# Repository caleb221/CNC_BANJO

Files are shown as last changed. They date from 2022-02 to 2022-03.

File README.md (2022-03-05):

# CNC_BANJO
This is a full sized 5 string Open Back Banjo I decided to make.<br>
It uses nylong strings, planetary geared tuners, a calfskin head and is Texas themed.<br>
The rim and neck are both made from Poplar, while the fretboard is made from Oak.

 
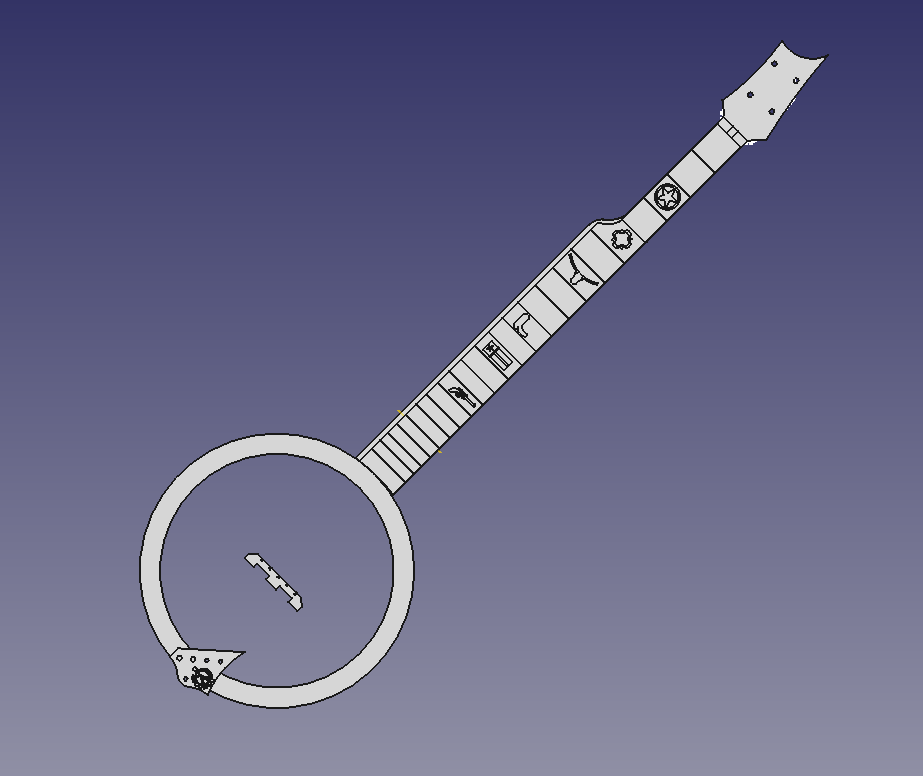
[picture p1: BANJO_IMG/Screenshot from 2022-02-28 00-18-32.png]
 
 

# Model
  The banjo1.fcstd File is the CAD File for the whole banjo.<br>
  
  Fret lengths were found using the <a href="https://www.ekips.org/tools/guitar/fretfind2d/">FretFind2D Tool</a>. 
 
  A scale length of 26.375'' or 669.925mm was used.
  
  This is a standard full sized 5 String Open Back Banjo.
  
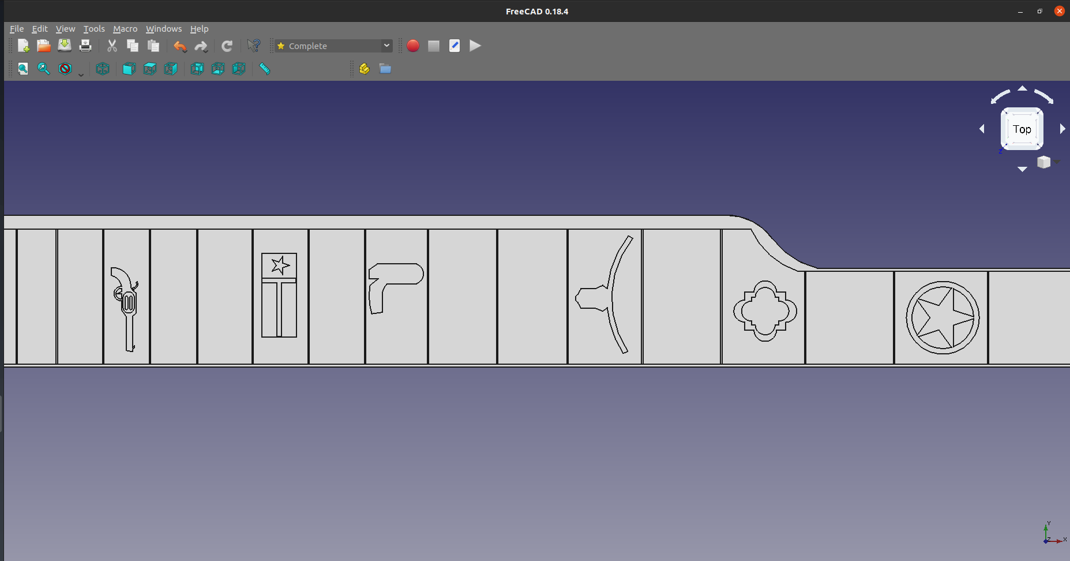
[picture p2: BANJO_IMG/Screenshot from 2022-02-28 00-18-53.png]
  
  
# BUILD

  <b>RIM Ring:</b><br>
   To prepare the wood from a stick to a ring (without a steam bender or lathe)
   first cut out 8 segments of your wood stock according to<br> <a href="https://github.com/caleb221/CNC_BANJO/blob/main/NON_CNC_PLANS/BluestemBanjoRimSegmentGuide.pdf"> Blue Stem Rim Segment Guide (copy)</a>.
   I cut 36 segments of the 8 segment 11'' rim, which totaled 4 rings and a depth of about 3'' for the rim.
    
   Glue the segments together using either a jig (probably better) or a band clamp which is what I used.
   
   After the glue dries and all 4 segments are prepared, use the CNC to cut out the rings.
   
   Once the rings are cut, use the dowel holes to line up the rings and glue all 4 segments together.
   
   Once you have what should look like a rough rim, use the CNC as an upside down router table to smooth things out on both the inner and outer diameters.
   I used a flush trim bit to do this.
   
   Once it is flush, I cut a small lip around the outer diameter. 
   
   Once this process was finished, I measured out the angles needed for the hardware.
   
   This can be found as the hardware_angles array in teh freecad file
   
   I used the drill press to make these 8 holes. Along with 2 7/16'' holes on each end for the 1/4'' threaded dowel rod, tailpiece and neck attachment.
   
   <b>I had pictures of this process, but halfway through my phone decided to die, losing those pictures forever</b>
    
   
    
    
    Note: The model is a bit oversized, which allows for discrepencies that arise when the rings are glued together and so that the 11'' inner diameter can be reached using the flush trim bit.
    Most of the wood preparation measurements can be found in the NON_CNC folder.
    There are also bits of information on building jigs and how to make one without a CNC.
    
  <b>RIM Hardware:</b><br>
    <br> 
    <b>Tension Hoop:</b>
      
    Get the 3 foot Steel flat bar and bend it into a ring.
    
    Use the rim to measure the exact size of the ring, and mark it. It should be oversized by a few inches.
    
    place the bent steel into a vise where it can be brazed together.
    
    The inner part of the steel bar should meet the measured mark, with the excess on the outer part.
    
    Heat the steel ring until it is red hot and braze the steel with flux and a bronze rod. 
    
    Use an Angle grinder to remove the excess flat bar, and deburr across the top.
    
  <br>
    
  <b>J hooks and Brackets:</b>
  
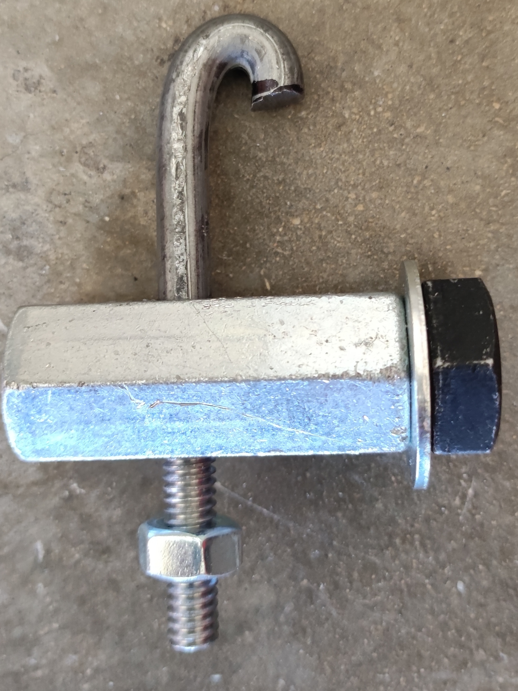
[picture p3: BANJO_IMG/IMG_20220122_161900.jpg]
   
   
   Measure the approximate depth of your rim and use it for the length . 
    
   Grab the 1/4'' steel rod and put it into a vise. 
    
   using as little rod as possible create a 90 degree bend, then hammer that bend until you can see a clear hook.
    
   Cut of the excess in the hook using an angle grinder, and cut it to length (should be approximately 3/4 your rim depth).
    
   Thread at least 1/2 the length of the J hook using 1/4'' round die and cleaning with a 1/4'' hex die..
    
   Repeat until you have 8 hooks

   Use one 1/2'' coupling nut, a 1/2'' bolt and appropriate washer and thread it into place in the rim blank.
   
   Once it is in, get your steel hoop and place it where it fits snugly onto the rim.
   
   Grab a J-hook and measure the approximate location in which it will hold the hoop and sit in the coupling nut.
   
   The coupling nut should be much longer than desired.
   
   Use the mark from the J-hook to determine how much excess there is in the coupling nut.
   
   Cut out the marked hole through the coupling nut with the drill press.
   
   Use the angle grinder to cut off the excess markings on the coupling nut.
   
   repeat until you have 8 brackets.
   
   Determine if your bolts fit snugly without hitting the J-hooks, mine where a bit too long.
   
   If needed, cut down the 8 bolts to a length where they will tighten down fully without touching the J-hooks.
   
    
     
  
  <b>RIM Finishing steps:</b><br>
  
  At this point, apply any wood finish desired to the rim and let it dry. I used Boiled Linseed Oil and some minwax golden Oak.
  
  Once dry (a few days usually), test how the hardware fits together, make sure all hooks grab onto the tension ring.
  
  Also make sure the tension ring holds down the flesh hoop tightly.
  
  Disassemble and prepare the parts for the last time.
  
  Soak a calfskin (at least 13'' in diameter) in warm water for at least 30 minutes.
  
  Wrap the skin in the flesh hoop and get it in place on the rim.
  
  Put the tension hoop in place along with the J-Hooks.
  
  
  
  
  Tighten the J-Hooks <b>SLOWLY</b>. 
  
  Cut off the excess skin using a box cutter or any knife.
  
  
  
  The skin will dry out over the next day, tighten as it will allow.
  
  <b>NECK:</b><br>
  
  Glue up the appropriate boards. I used Poplar but any hardwood will do great!
  
  Cut out the neck blank using the CNC. This will require you to flip the workpiece.
  
  The top side should be cut first as it contains the "truss" rod and that must be centered within the neck.
  
  Cut the backside. Round out the edges with a 3/4'' roundover bit.
  
  Cut out the heel blank, glue it to the neck blank using dowels to align.
  
  Glue the 3/4'' steel square bar into the neck using silicon or glue of your choice.
  
  
  
  Cut out the appropriate headstock holes.
  
  Cut out the 5th string peg.
  
  Drill 2 holes at a 5 degree angle for the hangar bolt attachment to the rim.
  
  <b>Finger Board:</b><br>
  
  Prepare any 1/4'' hardwood slat onto the CNC.
  
  Cut out the artwork and contour, then backfill the artwork with epoxy resin.
  
  
  
  
  Fret the neck or fill in the fret slots with epoxy for a "fretless" banjo.
  
  level, sand, and crown the frets if thats the way you went. 
  
  I had enough fret wire for 12 frets, and the rest are epoxied in. A half and half compromise
  
  Glue onto the neck.
  
  <b>MISC:</b><br>
   Flesh Hoop: I used a 1/8'' Brass rod threaded and held together with a coupling nut.
   
   TailPiece: I used extra wood from the fretboard and a copper wire tied onto a 1/4'' bolt sticking out the back. 
   
   Bridge: While I did design this, I used a bridge I had obtained earlier from a banjo I built in High School.
   
# Tools
    Open Builds LEAD1010 CNC (or anything 
    Drill Press Vise
    Drill Press (the cheaper harbor freight one did this job just fine for me)
    Angle Grinder
    Power Drill
    MAP/Butane Blow torch
    Taps / Dies (SAE 1/4'' and 1/8'')
    Pull Saw
    Draw knife / spokeshave 
    Wood/Metal Rasp
    Metal Files
    Miter Box with 22.5 Degree slot
    Clamps
    Safety stuff
# BOM
    Poplar wood (1''X3'' X ~14' is what I used)
    Oak wood  (1/4'' X 3'' X ~4')
    Calfskin 16'' diamter (thin, but a thick one would work just as well)
    1/4'' steel round stock ( ~5 Feet)
    1/4'' steel square stock (~3 feet)
    1/8'' Brass rod 
    1/2'' coupling nuts
    1/2'' X 1'' Bolt
    1/2'' Flat washer
    18 guage steel flat bar
    1/4'' hanger bolt
    1/4'' coupling nut
    1/4'' X 1' threaded rod
    1/4'' nut
    1/4''X 2'' bolt
    1/8'' coupling nut
    Fret wire
    Imitation bone Nut blank
    Banjo Planetary tuning pegs (with 5th string peg)
    bridge (if not making the one designed)

# Consumables:
    Epoxy Resin
    Brazing Rods
    Super Glue
    Epoxy Resin
    Mica Powder
    Boiled Linseed Oil/Japan Dryer
    Sand Paper





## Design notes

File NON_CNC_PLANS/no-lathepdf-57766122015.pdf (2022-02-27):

# No lathe? – No Problem!

J. D. Michne

I was in the Northeastern Woodworkers Association (NWA) Learning Center, teaching some members how to build a cedar stripped canoe. There were some other members working on banjoes in Ken’s class there. That looked like a neat woodworking project, so I told Ken if he ever did another class, sign me up. He did, and since I was between building boats, I became a novice luthier. I don’t need a banjo and can’t play one (yet), but the craftsmanship challenge would be exciting.

Ken’s method of building the rim consists of accurately cutting six identical blocks with 30⁰ angles on the ends, and gluing them together into a perfect hexagon. Make three or four assemblies, and then glue the whole stack together.

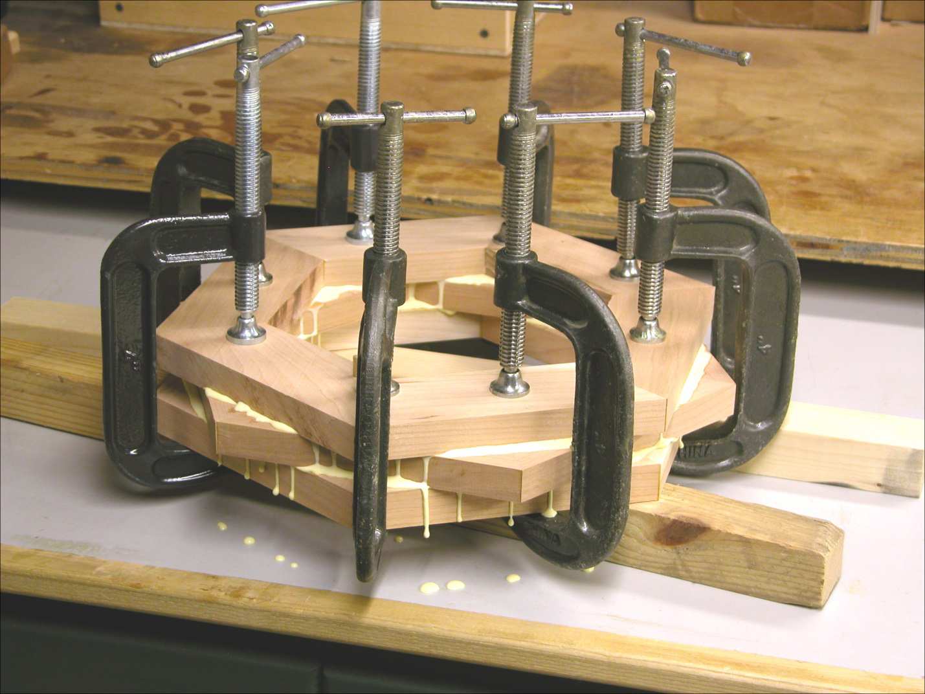
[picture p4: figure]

Then we rough-cut the outside round to just a bit oversize on a band saw. One of the students brought in a long-bladed jig saw, and roughed out the inside to near round. The whole thing was then mounted on a backer board and faceplate and turned round on a lathe. Another lathe session two weeks later brought the piece to perfectly round at the correct final dimensions.

Ken’s classes are every other Friday afternoon, so there was a lot of time between sessions. When I have a lot of extra time, I think. When I think, I can be dangerous…

What if one of the joints in the hexagon was not glued, then sprung open enough to slip the band saw blade though it? Cutting the inside of the individual rings would be easy. For that matter, if the rings were cut accurately enough to require just sanding to final dimension after gluing, the need for a lathe would be eliminated. Furthermore, the width of the blocks required to get a circle out of a polygon would be reduced if there were eight blocks instead of six. Off to the computer and CAD. I drew two concentric circles ³
/4" apart, and then surrounded them with an octagon inside and out.

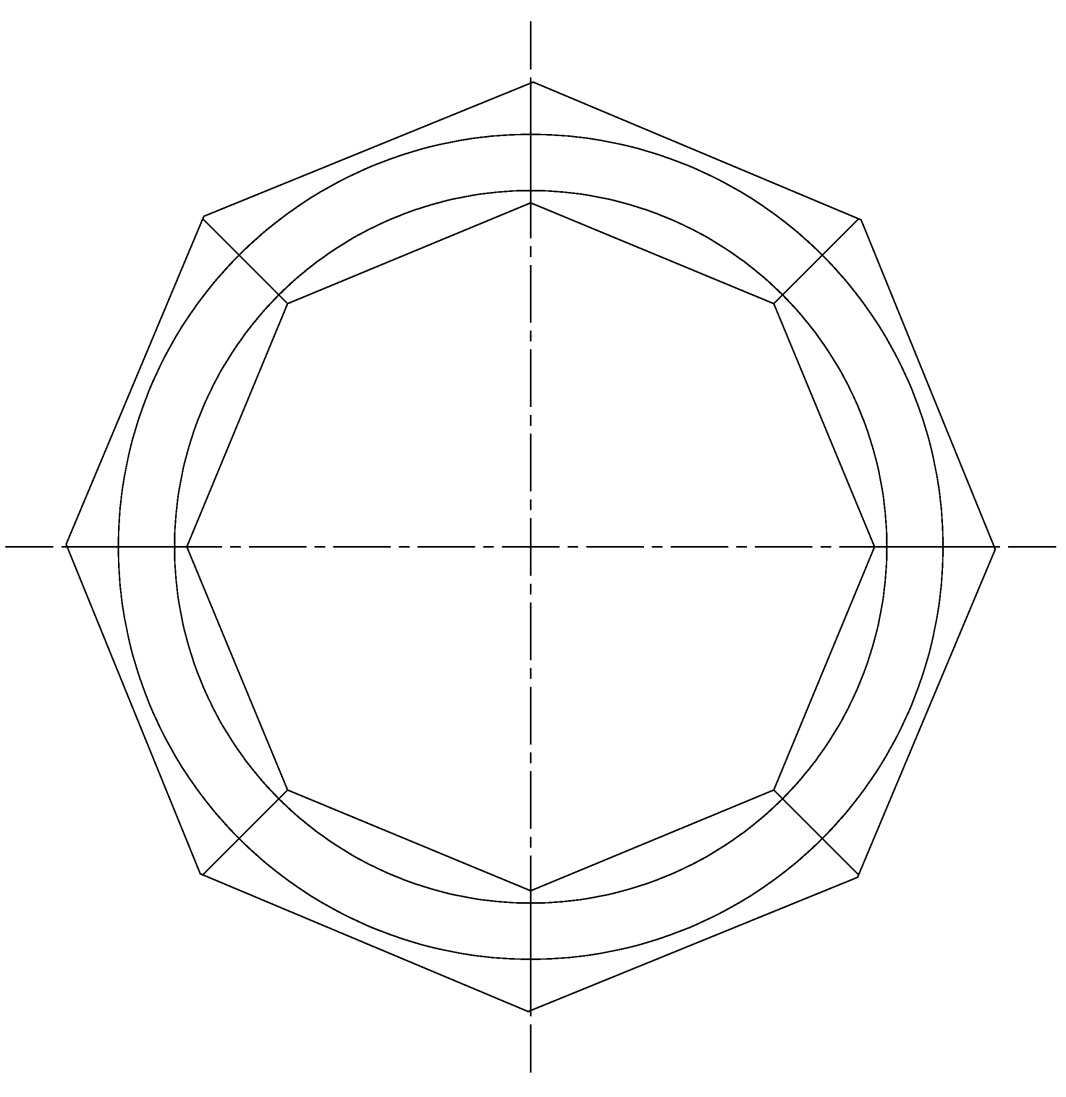
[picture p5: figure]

The dimensions of the segments are 1¹

/2" wide, 4³
/4" on the long side, and a complementary angle of 22¹
/2

⁰ between the long side and the cut ends. The ring is 11" outside diameter, ³
/4"
thick¹
. With the dimensions now defined, I could use a sled to cut the identical segments on the table saw.

I had a sled set up to cut the 30⁰ angles for my class banjo, so changing the angle to exactly
22¹
/2⁰ was next. How was I to get that angle, and as close to exact as possible? Without some sort of reference device, it would have to be by trial and error, commonly called “sneaking up on

1

In Ken’s class, resonator banjo rims are ³

/4" thick; open backs are 1
/2".

it”. I made sure the miter gage on the table saw was exactly square to the blade (the plate, not the teeth), and the pointer on the head was set exactly to 0⁰. Then I rotated the miter gage head so the pointer was as close to 67¹
/2⁰ as I could estimate, and locked it. I cut that angle on a piece of ¹
/4" plywood, and used it as a preliminary reference to set up the sled. I cut the reference piece the same width as the desired blocks, and around a foot long.

The sled looks like this, showing a few blocks already cut and another being run through:

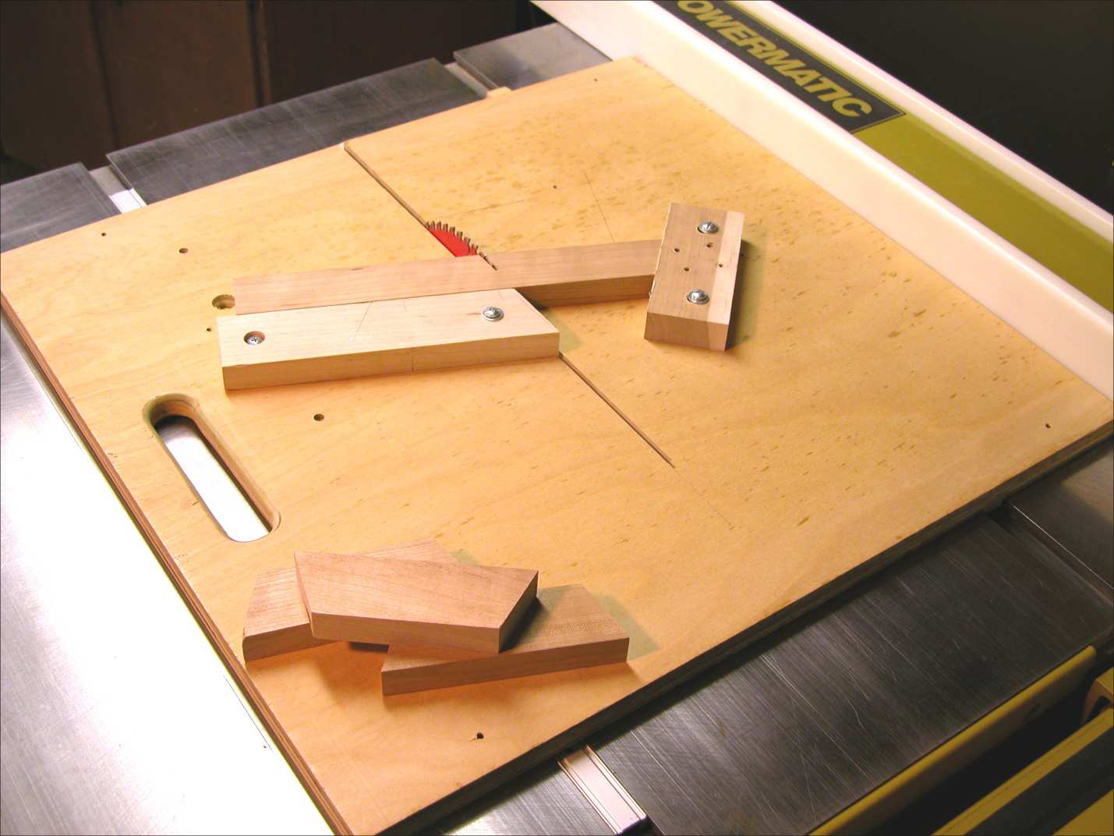
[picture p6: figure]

The base is ³
/4" hardwood plywood, shop-acclimated and flat. I added an additional bar to ride in the second miter gage slot on the saw table, so that the blade was approximately centered on the base. The sled has to be rock-solid yet slide smoothly with no side-to-side slop, so I butted the saw’s fence up to the edge of the base and locked it.

To determine the initial placement of the infeed fence, I set the angled end of the plywood reference against the blade and scribed its edge on to the base with a sharp pencil. The infeed fence was screwed to the base at the scribed mark with two screws – the one on the left is a pivot, and the one on the right is through an oversize hole. This permits a slight amount of play that can be used to fine-tune the cutting angle before tightening the screw. The piece used for the fence was initially longer than needed so that it extended beyond the cut line. It was trimmed after it was mounted.

The outfeed stop block is simply a convenient piece of scrap wood screwed down as a stop. Its position defines the length of the cut segment, which can be determined using the plywood angle reference. Simply make a mark on the reference at the proper dimension (4³
/4" on the long side)
and align the mark at the tip of the outside of a saw tooth as if it would be cut, and screw the block down. Both screw holes are over-size, again to permit minor adjustments.

This is a good place to mention some nitty gritty details easily overlooked. Ignoring them can result in problems as you go along. Remember, using a lathe produces the perfect round. We want to be able to come as close as possible to perfectly round without a lathe. Achieving this requires your tools to be set up as precisely as possible.

First, the table saw must be accurately aligned – fence parallel to the blade, blade parallel to the miter gage slot and square to the table. A good sharp blade capable of making smooth cuts is essential. I prefer the 7¹

/4" Freud Diablo D0760R, 60 teeth, with a ¹ /16" kerf. The band saw table must be square to the blade, and likewise for any sander you may use. The jointer tables must be aligned and the fence square to the tables. Test cuts in scrap will show the need for any adjustments.

The sled now has to be set up to make perfect cuts. This may take a while, but if you were lucky making the reference piece it should go well. Using scrap wood, make some pieces 1¹
/2" wide
and a couple of feet long. They should be ³
/4" thick, but need not be precise. We only want to verify the cutting angle – 1-by pine will do.

Make an angle cut on one end of a test piece. Insure there are no chips or sawdust anywhere on the sled where the stock will be placed. A chip brush works well here. Positioning the stock for the next cut with even a small chip under it can cause a skewed cut. Rotate and position the test piece on the sled with the cut end against the stop block, and cut a block. Any time you are about to make a cut, make sure the cut end is firmly against the stop block, and the stock is held tightly against the infeed fence. The goal here is reproducible precision in the cut blocks. Make eight blocks.

Dry-assemble the blocks into an octagon on a flat surface and clamp them as if they were a glue-up assembly. The Merle clamp works well in Ken’s class, but at home, I use a band clamp with shop-made shaped clamping cauls at the joints. (See the picture on the next page.) Examine the clamped assembly closely. There should be no gaps anywhere and the corners should all align. Press each piece to the table to ensure all surfaces of the assembly are in the same plane. If there are any gaps, the cutting angle of the fence needs adjustment. Loosen the screw closest to the blade, and very slightly pivot the fence just a hair one way or the other depending on where the gaps in the assembly are. This adjustment should be just barely perceptible. Then try again. Don’t try to trim the ends of each block – this is a safety issue.

If all is well, you could start on the real thing, but don’t do it yet. Use full-size test pieces to assemble an octagon before committing to the real wood. Apply glue liberally to each joint except for the last one. Leave this joint dry, and clamp the assembly together. The dry joint will be tight when the glue cures and the clamp is released. This joint will become the gateway for the band saw blade for sawing the inside round. Don’t try to spring the joint open just yet. Forcing it open could cause a failure in one of the glued joints. Simply mark the joint for now. Let the glue dry for about 30 minutes, and remove most of the squeezed out glue with a putty knife. This makes it easier for drum sanding later. The heat of sanding softens the glue, which then gums up the sand paper.

With the cutting angle set and a successful test glue-up, the next step is to make wood for the real thing. That is, joint one surface of the raw stock, then joint one edge square to the jointed face, thickness plane the raw surface to bring it parallel to the jointed face, and finally rip it to final width with the jointed square edge against the saw fence. This is a very important sequence. In order to get perfect glue joints on a flat and uniformly thick assembly, the component parts must be straight, flat, square, true, level, plumb, dry, etc., - “close enough” not allowed.

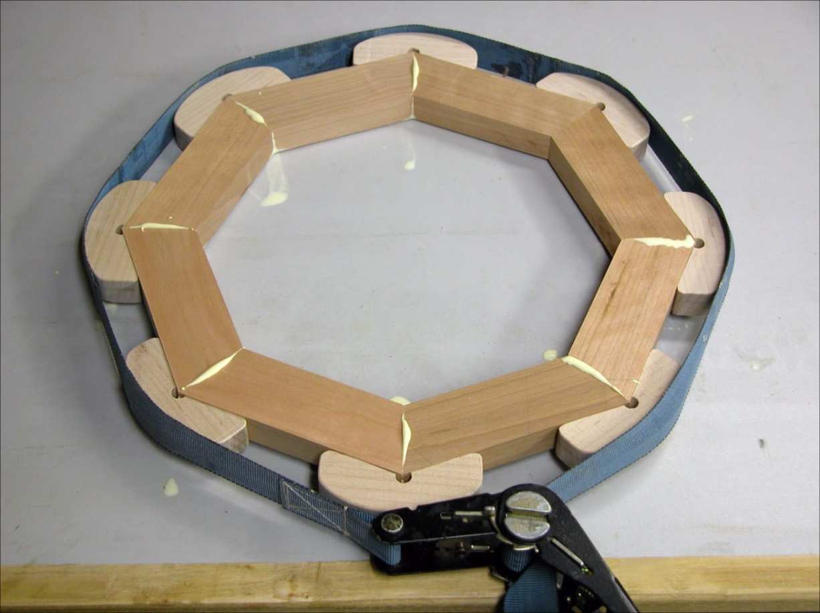
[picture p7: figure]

Glued octagon – Note the one dry joint.
How many assemblies are needed to make a banjo? If the wood is nominally ³
/4" thick, four
rings in a stack will yield a pot about 3" high. The top ring will be either shaped for a metal tone ring or chamfered for using the top ring as the tone ring. The bottom ring can always be thinned to the final desired height after assembly. For purposes of this discussion, I will assume four rings.

Scrape the dried glue off as much as possible without being surgical about it. It is better to leave a little bit rather than scraping a divot into the wood.

Drum-sand both sides of the assemblies. Examine the sanded surfaces closely, and repeat until the entire surface has the same texture and there are no glue remnants. You are now ready to make round rings.

The reference for turning a ring on the lathe is the axis of the lathe, which extends through the stock being turned. Whatever is turned about the axis can be brought perfectly round by the application of various tools. What is the reference for making a ring from wood without a lathe? The center of the circle is not defined, since it does not exist in a real object. The solution is to attach a temporary and reproducible reference center.

Note in the drawing on page 2 that there are two centerlines crossing at right angles. These lines also intersect joints in the octagon. For any opposing pair of joints, there are equivalent pairs of joints at exact right angles to it. Here is the solution to the reference center problem. By attaching a plywood disk cut in a perfect circle to the octagon, the center of the disk becomes the center of the octagon.

To make the reference disk, rip a piece of ¹
/4" plywood about a half inch wider than the desired outside diameter of the final ring. Without changing the table saw fence, turn the ripped piece 90⁰ and cut it again, producing a perfect square. Then very carefully draw diagonal lines across the entire piece of plywood from corner to corner. Take extreme care in doing this, use a fine point pencil, and make sure the lines do indeed intersect the corners as near perfect as possible. The center of the square is where the lines cross.²

With a center point now defined, the disk must be cut out from the square. An easy way to cut it is with a band saw fitted with a circle-cutting jig. There is any number of such jigs around in woodworking publications; I prefer the easily adjustable version from ShopNotes magazine.³ Drill a small hole at the center of the square to fit the pivot pin of your jig, and cut out the circle. Extend each of the centerlines across the edge of the disk, and whittle a bevel about an inch long and a sixteenth wide somewhere on the edge opposite the side with the lines on it. Its purpose will be described later.

Next is to align the circle so that its center is at the center of the octagon. Attach four pieces of approximately equally spaced double stick tape to the test octagon, and lay thin spacers of plastic or wood between the tape pieces. Lay the disk on to the test octagon, and align all four centerline marks exactly over four joints in the octagon. The easiest way is to first align two vertical marks, then move the disk up or down to align the horizontal marks. When all four marks are aligned with joints, press down on the center of the disk so that it does not move and remove the spacers. Apply pressure all around the disk to ensure it is firmly held by the tape.

2
Aren’t you glad you took geometry in school?
3
ShopNotes.com, back Issue No. 15

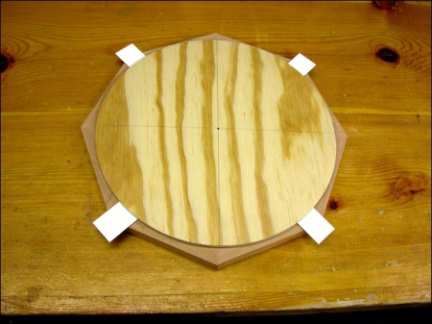
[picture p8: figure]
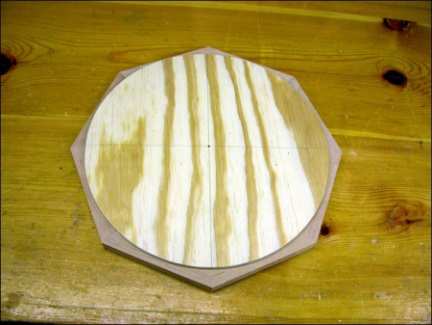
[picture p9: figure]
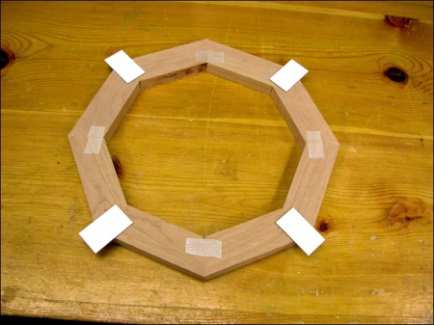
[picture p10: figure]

With the jig in cutting position on the band saw table, adjust the position of the pivot to make the cut about ¹
/16" larger than the final radius of the ring. The extra width is for disk sanding the final assembly of four stacked and glued rings. Cut the ring from the test octagon, and examine the result. If all is well, make and cut the real thing. If the diameter of the cut-out is not as desired, make a correction to the pivot placement before cutting the real thing.

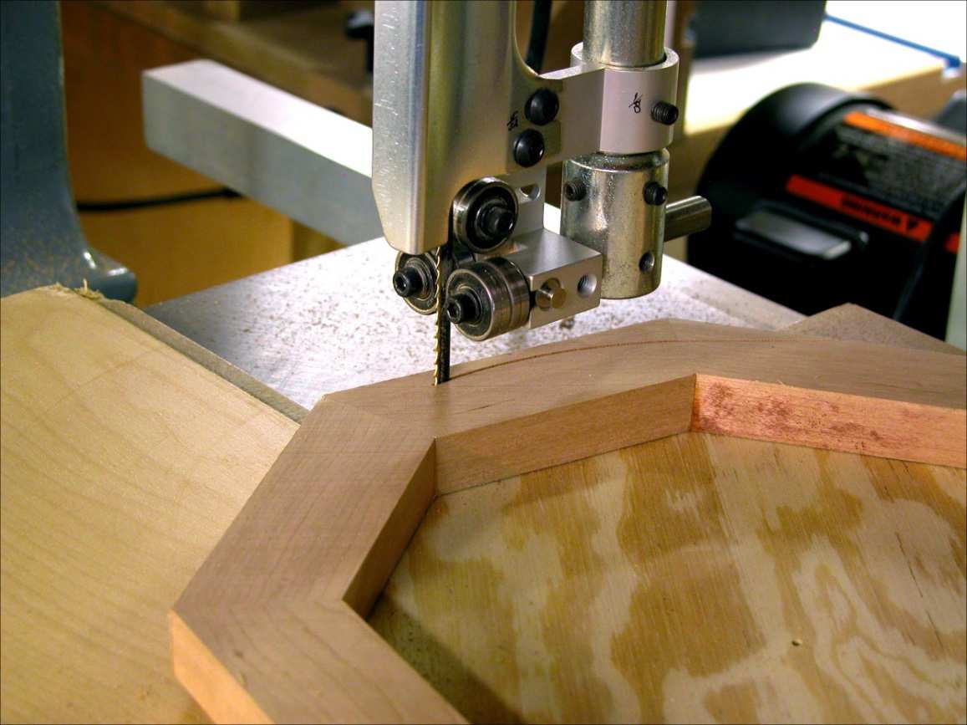
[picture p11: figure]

That little bevel you whittled on the edge of the reference disk now comes in handy. Insert a thin wedge into the bevel and slowly push it in under the disk. This gently separates the disk with little or no damage to the tape, allowing possible re-use.

Now you are ready to cut the inside.

The cut can be made freehand after making a reference disk to mark the inside cut line, or cut with greater precision using a simple jig shown below. Two pegs in the jig are used as guides for rotating the ring as the inside is cut; the other two are for cutting the inside of a resonator ring.

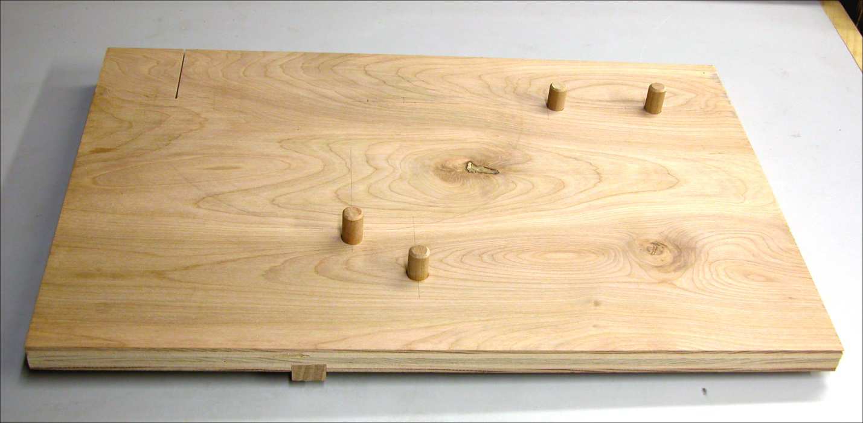
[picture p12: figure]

Start with a flat piece of ³
/4" plywood, 12" x 18". On the band saw, measure the distance from the blade to the miter gage slot. Add 2¹
/2" to the measurement and install a runner that distance from the left edge of the board that will fit the slot. Place the board on the saw table with the runner in the slot, and cut a kerf about 2¹
/2" long. Turn off the saw, but don’t move the board. Mark the location of the edge of the table on the underside of the board, remove it, and install a stop block at the mark.

The end of the kerf is the reference for laying out the position of the guide pegs. The pegs are
1

/2" dowels 1¹
/2" long, driven tight or glued into the board. The leftmost peg interferes with cutting a resonator ring, and therefore must be removable⁴

To locate the pegs, it can be done by measurements or by using the test ring for the layout. The pegs at the top of the board in the above picture determine the diameter of the inside of the cuts; the two lower pegs keep the rings and blade aligned during the cuts (rim rings and resonator).

For a banjo rim 11" OD and ³
/4" wide, the peg on the right in the above picture should be centered at 10¹
/2" from the blade on a line beginning at the end of and square to the kerf. This, of course, is theoretical and assumes the outside has been cut and sanded to final dimension. Don’t do it. Any allowance for later sanding the completed rim round to final dimensions must be accounted for before placing the pegs. An easier way is to cut the inside of the test ring without the jig, and use that to determine final peg positions. The bottom pegs are located half the distance from the blade to the right pegs, and half the outside diameter of the rings below the blade/peg line.

Start by making a plywood reference disk the desired diameter of the inside, center it on the test ring as previously described, and trace it onto the work piece. To cut the inside, position the outside of the ring behind the blade without the jig, with the dry joint facing the back of the blade. Carefully pull the joint open just enough to allow the joint to be passed over the blade.

4
The removable peg should be a tight fit, requiring a mallet to drive it in or out.

Cut the inside of the test ring just outside the marked line, leaving an allowance for sanding. Remove it, again moving the ring from behind the blade. Now one would think that was easy – why bother with the jig? The jig permits much more precise and reproducible cuts, which means better alignment when the four rings are glued in a stack, and best of all, less sanding later of the glued up stack. It also contributes to an intangible component part – craftsmanship.

Starting the inside cut using the jig is nigh impossible, what with the pegs in the way. The solution is to start without the jig. The goal is to get the blade into the cutting position while the ring is against both pegs. Measure the distance from the blade to the top left peg. Make a mark on the work piece at this distance from the outside of the ring to the dry joint. Make a cut from about the middle of a segment, curving into the mark. Since the cut ends at the dry joint, a chip should fall away leaving the blade ready to cut the inside.

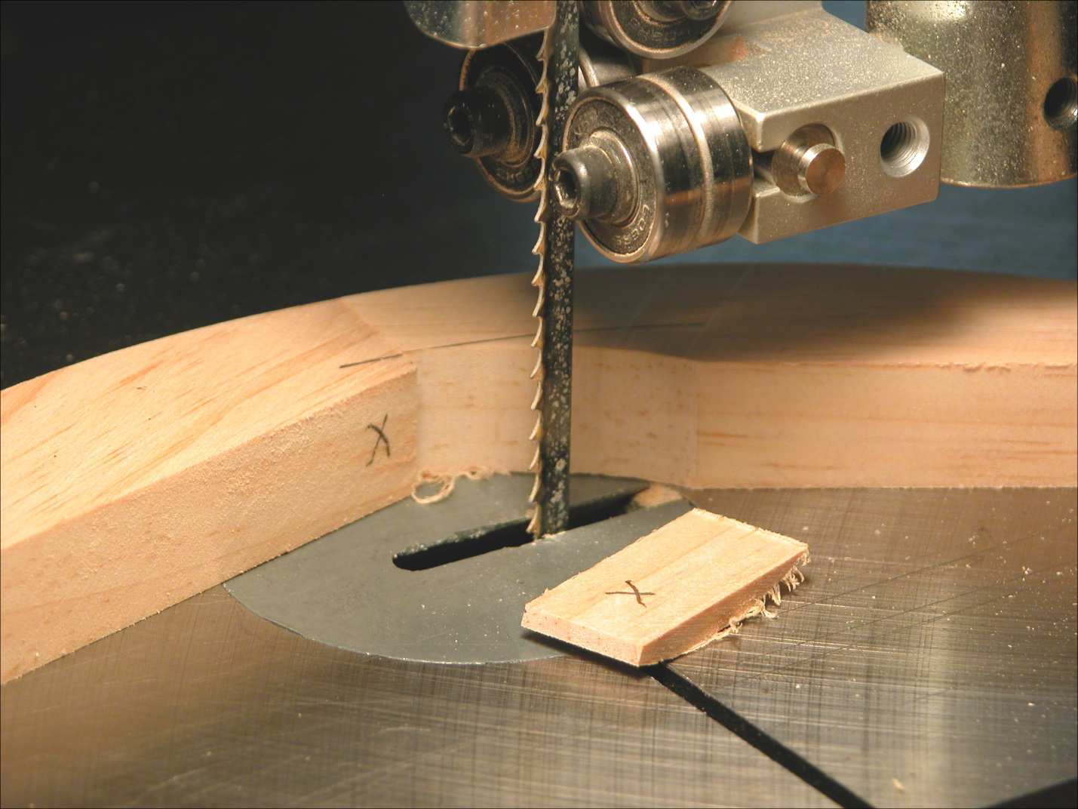
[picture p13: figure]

The clearance starting cut at the dry joint

With the clearance cut made, install the jig firmly against the table stop block. It is a good idea to clamp it to the saw table. Place the ring against the blade at the start position, and against the two guide pegs. Turn on the saw, and rotate the ring while firmly holding it against the pegs.

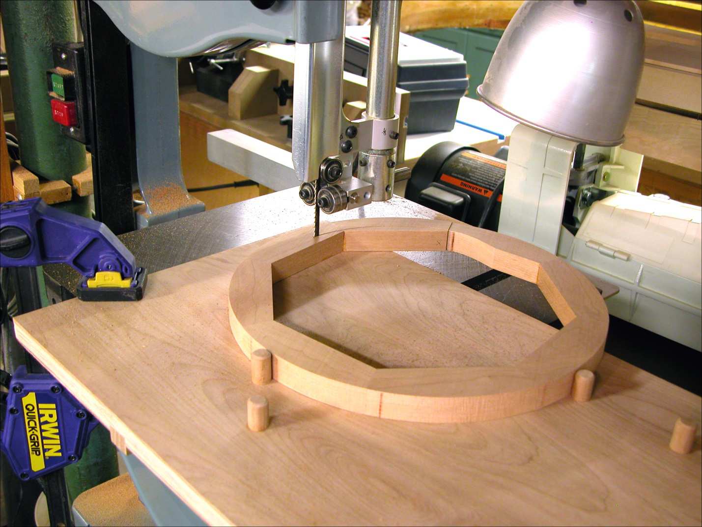
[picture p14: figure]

Cutting the inside of a ring

With the rings cut, spring the dry joints apart slightly and work some glue into the opening. Clamp them with web clamps (no cauls required) for an hour or so, remove the clamps, and clean up any glue squeeze out.

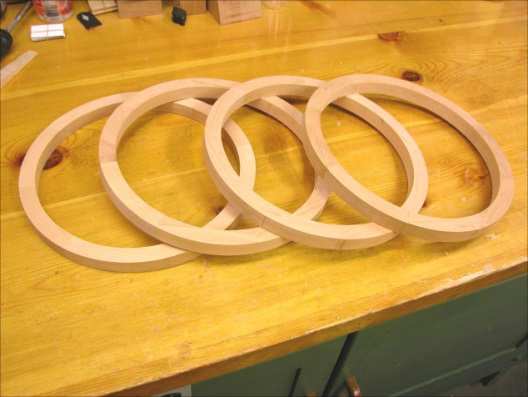
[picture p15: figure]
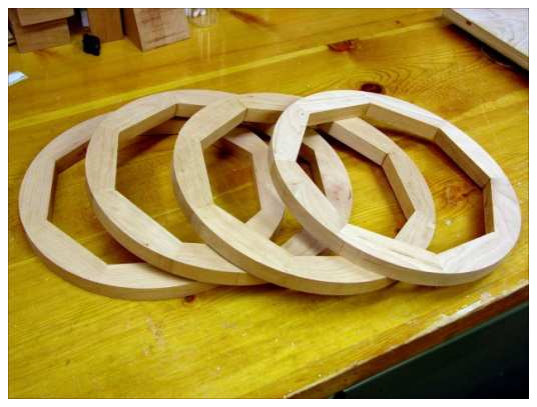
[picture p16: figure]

Next is to glue up the stack.

There are two considerations in gluing the stack together. First, how to prevent the slippery wet glued pieces from getting out of alignment when applying the clamps, and aligning the rings while building the stack.

Drive three ¹
/2" brads approximately equally spaced about half way into the tops of three rings, and clip off the tops. This leaves a sharp tit that will anchor the ring placed on top of it and prevent slipping in wet glue. The top ring should not have any brads.

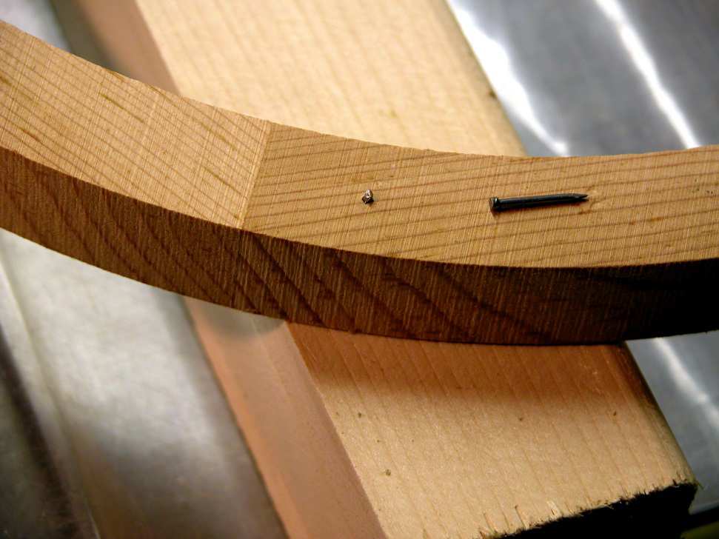
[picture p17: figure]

Half-inch brad, and one clipped
Next is to assure the alignment of each ring with the previous one while gluing the stack together. Proper alignment is essential, since removing wood on the outside due to a shifted ring on the completed glue-up requires the same amount of wood to be removed on the inside. The net result is a thinner pot than desired. I cobbled together an L shaped arrangement that will hold the rings properly aligned during assembly. It looks like this:

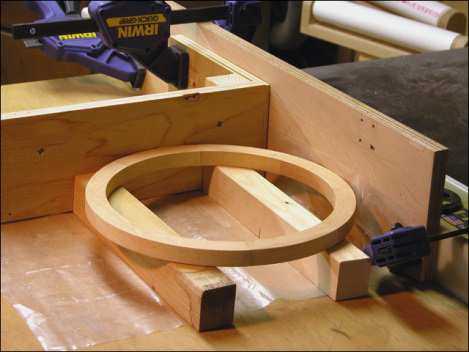
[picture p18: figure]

I started with a piece of plywood on my table saw table to protect the cast iron from glue drips. Then I laid down some sheet plastic as further protection. A tall temporary fence was clamped to the saw’s fence, and an L-shaped fence clamped to the saw fence to form a solid corner. Any ring placed in the corner will align with a previous ring, providing all rings are identically sized and touch the sides of the corner. Then I cut a pair of 2 x 2 supports that will raise the stack allowing clamps to be easily placed.

To do the glue-up, the bottom ring with the cut off brads facing up was placed as shown in the above picture, and glue⁵
applied. The next ring was carefully placed, holding the ring above the bottom ring while keeping it held against the corner. It was then lowered to the bottom ring, and pressed down so that the brad tips grabbed. The rest of the rings were added to the stack in like fashion.

Next was placing the clamps. I used 4-inch C-clamps, placing two or three to initially clamp the structure while still in the corner. The stack was now stable, so I removed the corner planks and placed more clamps. The stack now looks like this:

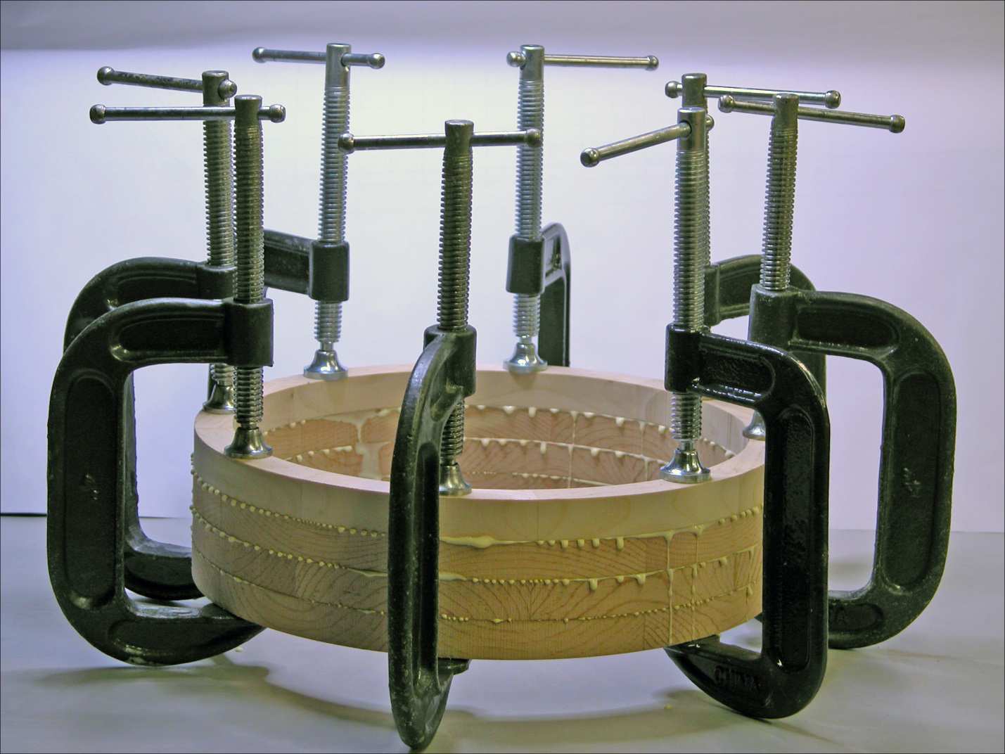
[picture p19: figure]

A scrap pine test pot

5
Original Titebond recommended

Let the glue dry for an hour or so, carefully remove the clamps, and scrape off as much partially dried glue as possible, inside and out. Set the assembly aside over night to let the glue cure completely.

Sanding the stack is another exercise in rotating it against a sanding medium in a manner that maintains it round. I found that for the outside, rotating it against a disk sander was not only simple, but also very effective. The disk sander should be loaded with a coarse grit. Since I use mine virtually always for shaping, I use 60-grit. The stack can be finished manually later to finer grits with a random orbit or finishing sander.

The disk sander has to be set up with a pivot point, which is adjustable for the distance from it to the disk. I have a moveable pin that came with the machine for sanding circles, which is functional, if not elegant. I fashioned a couple of adjustable stop blocks, one for rims and one for resonator rings, that prevent any further adjustment less than the desired outside radius of the pot. A screw in the end of the block can be turned in our out to tweak the sanding diameter.

In operation, the reference disk is retaped to the stack, and placed on the pivot pin. The pivot pin block is loose in the grove, but halted automatically by the stop block when the desired diameter is reached.

Sanding generates heat. Heat softens glue. Softened glue plugs up the sander, which in the extreme, can reduce the effectiveness of the operation to zero. By taking light cuts and cleaning the disk with a crepe rubber sanding eraser each time an adjustment is made, the sanding will be efficient, effective, and actually pleasant.

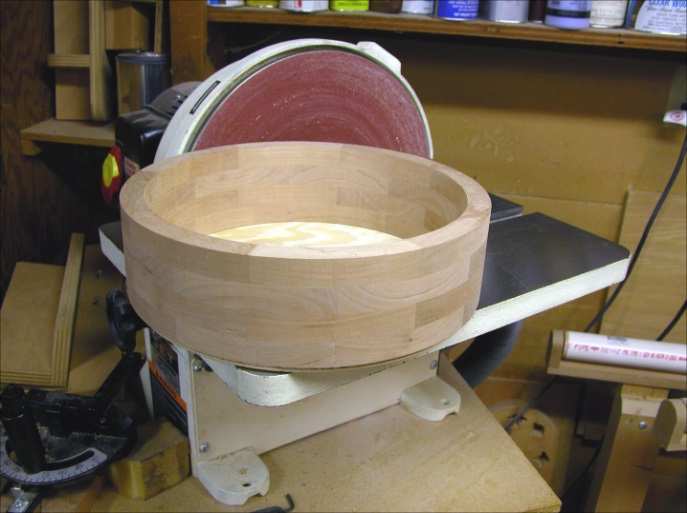
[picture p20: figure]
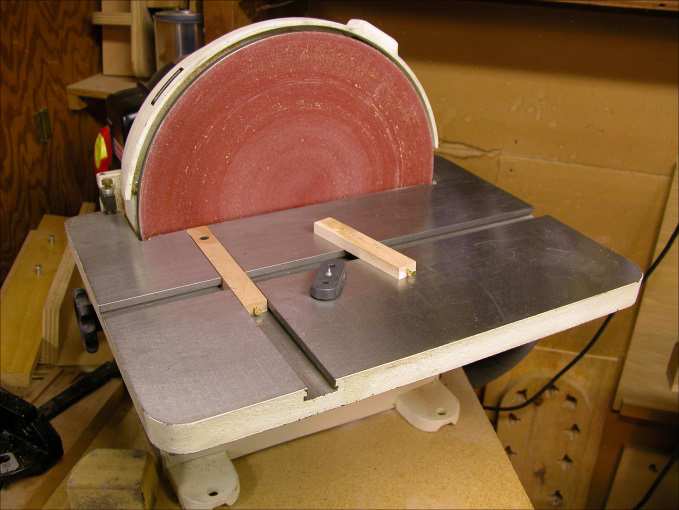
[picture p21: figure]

Adjustable pivot and stops | A finished pot
Cleaning up the inside was done with an oscillating spindle sander, with no particular attention paid to making it precisely round since there is nothing of great importance on the inside requiring it. I used a 2" coarse grit spindle. Sanding motion was such that roundness was very nearly approximated due to the random nature of the strokes. I swung the inside of the pot into the spindle from left to right, beginning the stroke against the direction of rotation of the spindle, and then changed to right to left, all the while keeping contact. I fed it rather rapidly so as not to end up with a divot. Imagine if you were sanding by hand, with a back and forth stroke at a medium speed. At the end of the stroke, I moved the pot away from the spindle, rotated it clockwise about as much as the length of the stroke, and continued the sequence until the sanding was complete.

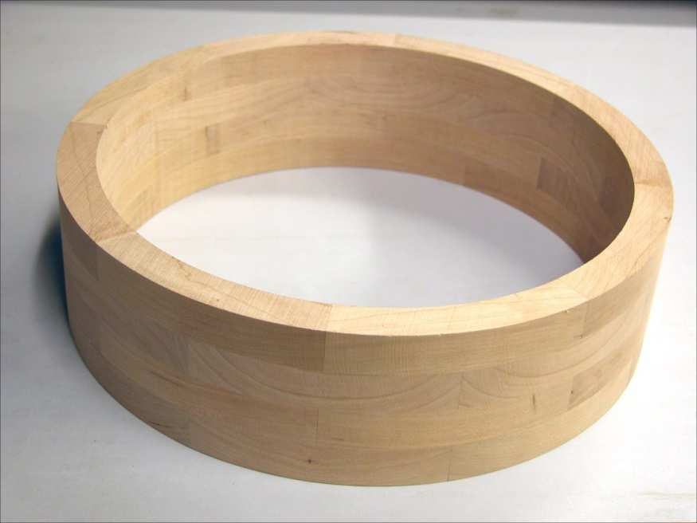
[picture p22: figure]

Almost finished cherry pot
There is still some shaping required before leaving the woodworking, with some questions to be answered first. Will the finished banjo be a simple open back, or fitted with a resonator? If it will be open back, will it have a metal tone ring, or a wooden one that can be made in the shop?

The easiest is the open back with a wooden tone ring, which is simply shaped on the top ring of the stack. A hardwood is usually used, and can be just about anything that will accept glue. I cannot speak for the exotic hardwoods, like bubinga, bloodwood, etc., since I have never worked with them. Maple is hard, cheap, and readily available. The test pot shown below has a black locust tone ring, merely because it is hard and I had a couple of planks of it from a tree in my front yard. Of course, the material for the tone ring must be factored into building plans, right from cutting of the blocks for the rings.

The requirements to shape a wooden tone ring are a router table fitted with a 45⁰ ball-bearing guided chamfering bit large enough to cut the chamfer mostly, if not completely, across the thickness of the ring. Start with the bit low in the table, with only about an eighth of an inch of the cutter exposed. Increase the cutting height no more than an eighth of an inch for each succeeding cut, until the chamfer is close to the outside edge of the ring. Sand the top of the ring such that there are no sharp edges remaining, and you are done.

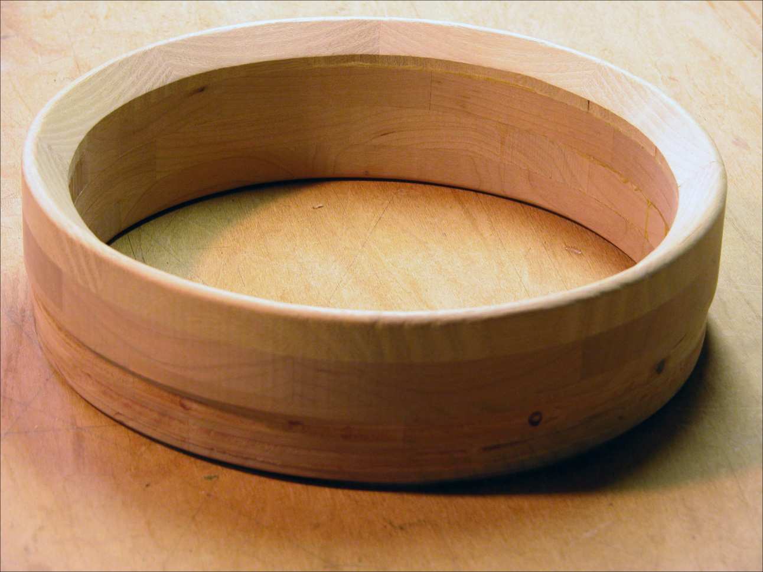
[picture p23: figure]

Chamfered wood tone ring on a test rim. I tried to cut a resonator flange rabbet by rotating the rim across the end of a router bit, without much success. Later attempts at cutting with the side of a router bit on other rims were much better

If a metal tone ring, such as the Five Star bluegrass flathead and arch tops described in the Stewart-MacDonald catalog is used, a rabbet must be cut in the rim to accept either. These items may have a lot of dimensional variability; therefore, it is highly recommended that the actual tone ring, and resonator flange if used, be available before starting the cutting.

A precision router table must be used, preferably one with a router lift capable of making minute adjustments in bit height. A good sharp ¹
/2" bit with a cutter length of at least an inch and a half is also required. An L-shaped fence should be clamped to the router table fence on the left side at a distance of one-half the diameter of the rim and against the bit rotation.

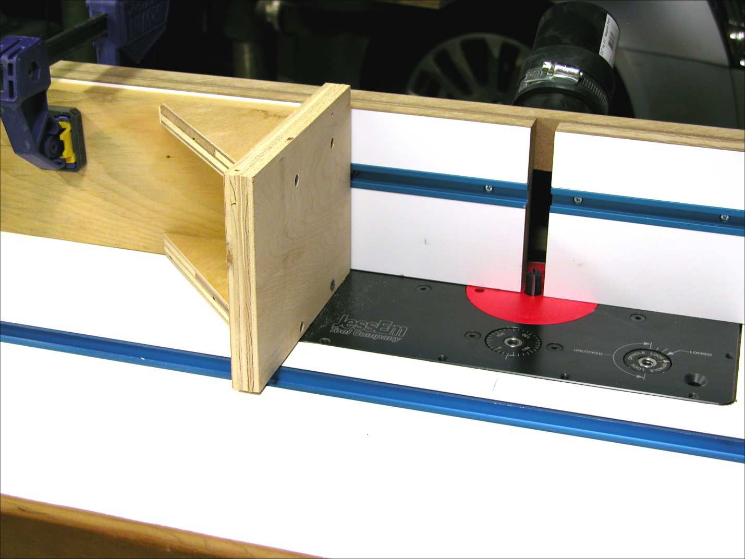
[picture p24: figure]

The fence should be initially positioned so that only about a thirty-second of an inch of the cutter edge is exposed, and the bit height is at about an eighth of an inch. With the router running, position the rim to the right of the bit and slide it into the cutter until it is firmly positioned against both fences. Rotate the rim counter clockwise one full revolution, keeping it against both fences. Examine the cut for consistent depth, and run it through again without changing bit position if there are any thin spots.

Try the fit of the tone ring. At this point, it should not yet fit. If it does just fit, the depth of the rabbit is correct. If not, the fence has to be moved back just a tiny amount and another pass made. Most table fences have a clamp at each end, which gives us a way to move the fence a few mils at a time. I marked the position of the fence near the right end clamp by making a pencil mark on the table against the fence. Then I loosened the clamp and softly nudged the end of the fence away from the bit a just perceptible amount, like a few mils, and made another pass. I kept repeating this sequence until the tone ring just fit the rabbet, which now sets the final cutting depth. Ken calls this “sneaking up on it”.

With the cutting depth of the rabbet now established, raise the bit about an eighth of an inch, and make another pass. Repeat the sequence until there is less than an eighth of an inch to go until the tone ring just rests on the top of the pot and the shoulder of the rabbet. Sneak up on it with small incremental raises of the bit until the ring rests equally on the rabbet shoulder and the top of the inside of the rim.

The whole process is then repeated to fit a resonator flange.

Done.

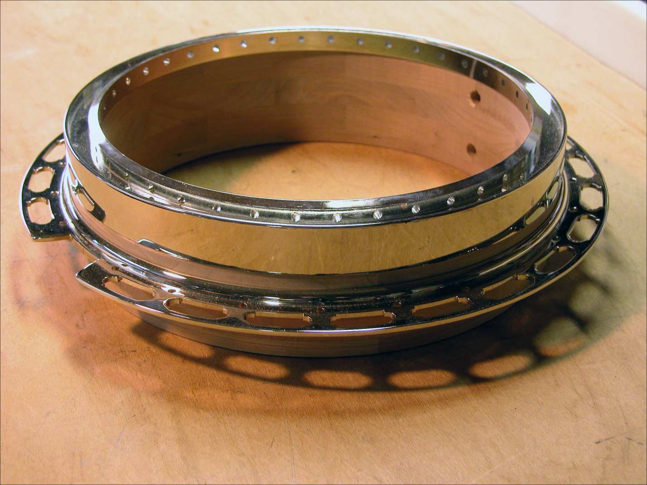
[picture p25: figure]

Finished pot. The rest is lutherie.

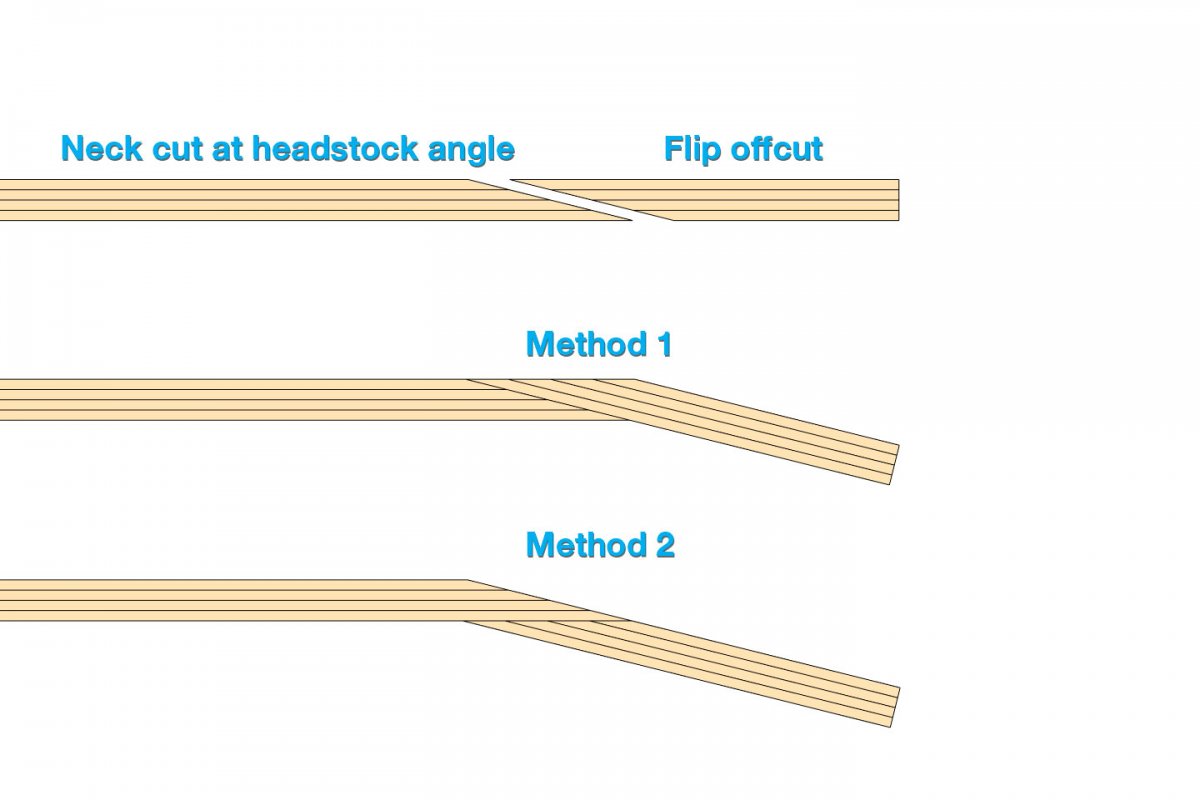
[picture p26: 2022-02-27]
NON_CNC_PLANS/neckJointANGLE6.jpeg

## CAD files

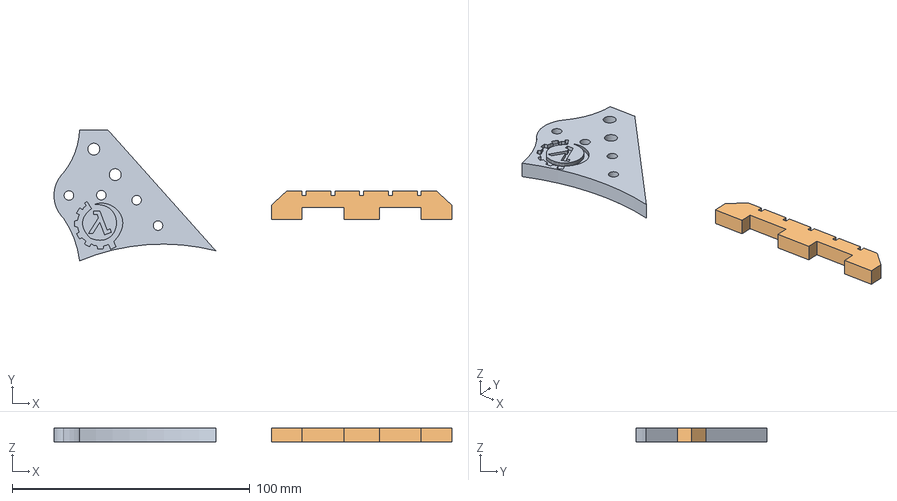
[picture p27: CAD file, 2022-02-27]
banjo1.FCStd
167.4 x 55.0 x 6.00 mm
Bridge

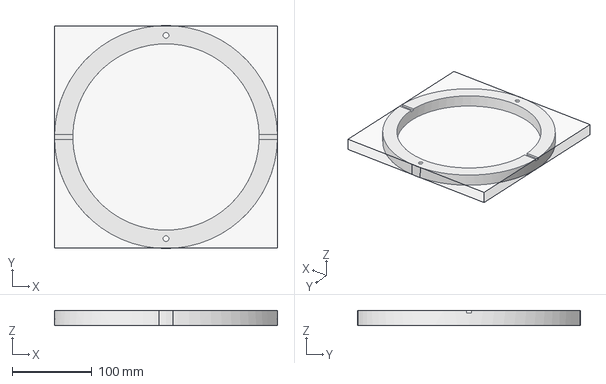
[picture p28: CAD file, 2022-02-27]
CNC_TOOLPATHS/banjo_RIM_CONSTRUCTION.FCStd
280.0 x 280.0 x 19.0 mm
Model-rimStock3
Stock

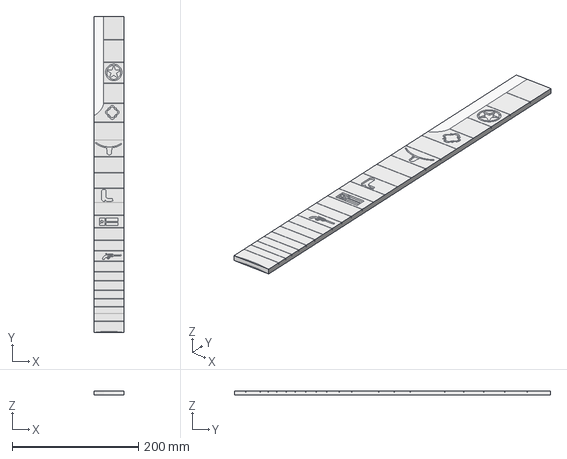
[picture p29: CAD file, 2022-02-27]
CNC_TOOLPATHS/banjo_FRETBOARD_CONSTRUCTION.FCStd
48.0 x 500.0 x 6.00 mm
Model-fingerboard1
Stock

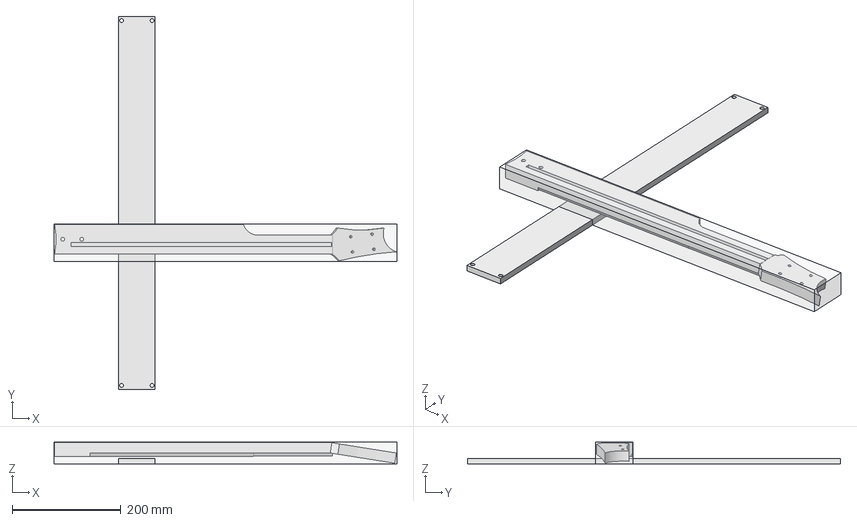
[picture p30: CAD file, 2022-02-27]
CNC_TOOLPATHS/banjo_NECK_CONSTRUCTION.FCStd
629.7 x 685.0 x 40.0 mm
NECK_STOCK
Model-Fusion
Stock

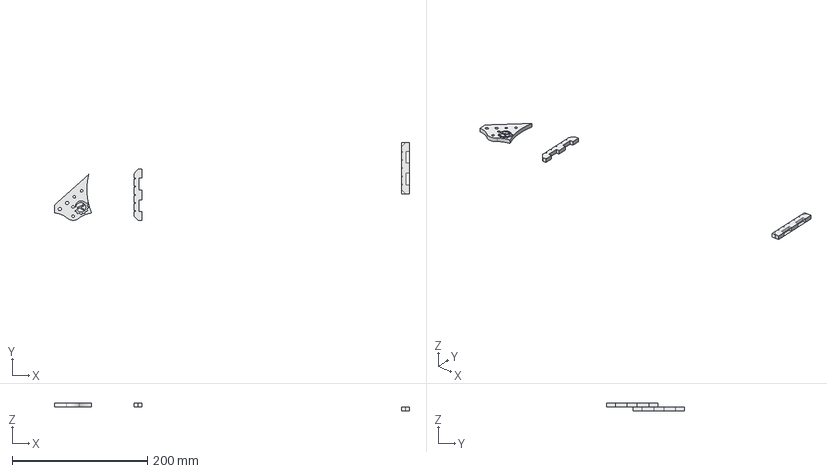
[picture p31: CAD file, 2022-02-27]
CNC_TOOLPATHS/BANJO_MISC_CONSTRUCTION.FCStd
525.5 x 115.5 x 12.0 mm
Bridge
Model-Bridge
Stock002

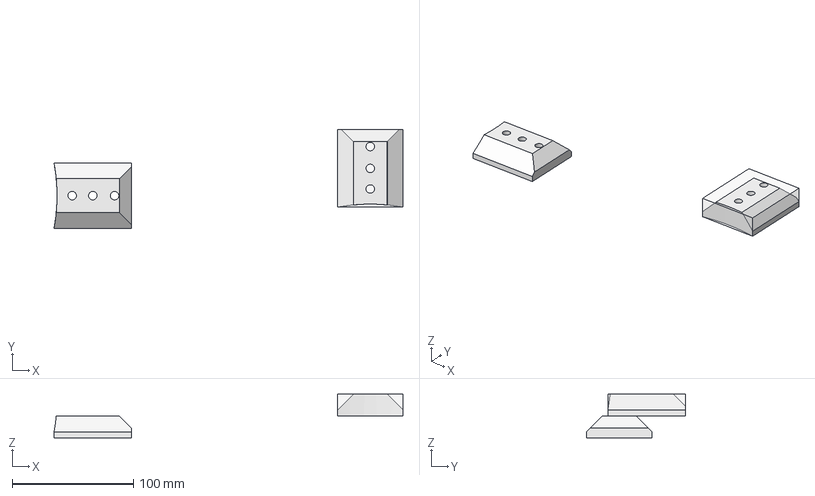
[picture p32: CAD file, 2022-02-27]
CNC_TOOLPATHS/banjo_NECK_CONSTRUCTION_FLATHEADFRONT.FCStd
288.0 x 81.5 x 36.0 mm
Heel1
Model-Heel1
Stock

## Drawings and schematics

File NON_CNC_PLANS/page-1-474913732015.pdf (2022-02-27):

# Bluestem Hand Drum Banjo Plan

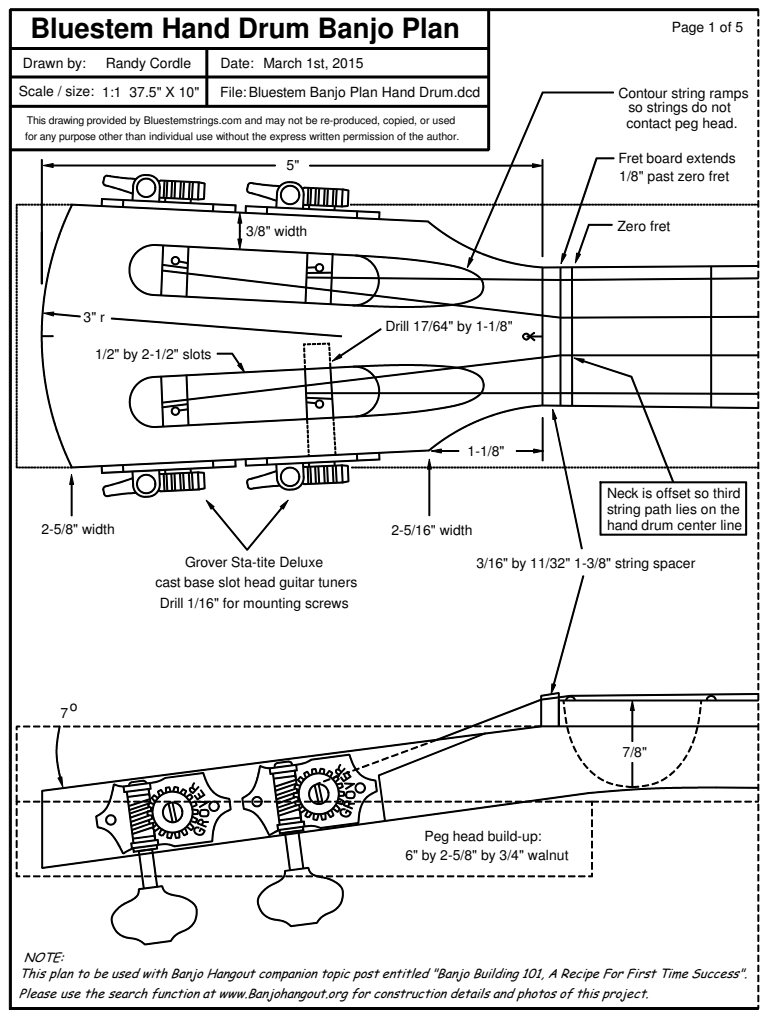
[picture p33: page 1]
Zero fret; 2-5/8" width; 2-5/16" width; 1/2" by 2-1/2" slots; 3/8" width; Drill 17/64" by 1-1/8"

Drawn by: Randy Cordle | Date: March 1st, 2015

Scale / size: 1:1 37.5" X 10" | File:Bluestem Banjo Plan Hand Drum.dcd

Contour string ramps
so strings do not
contact peg head.

This drawing provided by Bluestemstrings.com and may not be re-produced, copied, or used
for any purpose other than individual use without the express written permission of the author.

Fret board extends
1/8" past zero fret

Neck is offset so third
string path lies on the
hand drum center line

Grover Sta-tite Deluxe
cast base slot head guitar tuners
Drill 1/16" for mounting screws

3/16" by 11/32" 1-3/8" string spacer

Peg head build-up:
6" by 2-5/8" by 3/4" walnut

NOTE:
This plan to be used with Banjo Hangout companion topic post entitled "Banjo Building 101, A Recipe For First Time Success".
Please use the search function at www.Banjohangout.org for construction details and photos of this project.

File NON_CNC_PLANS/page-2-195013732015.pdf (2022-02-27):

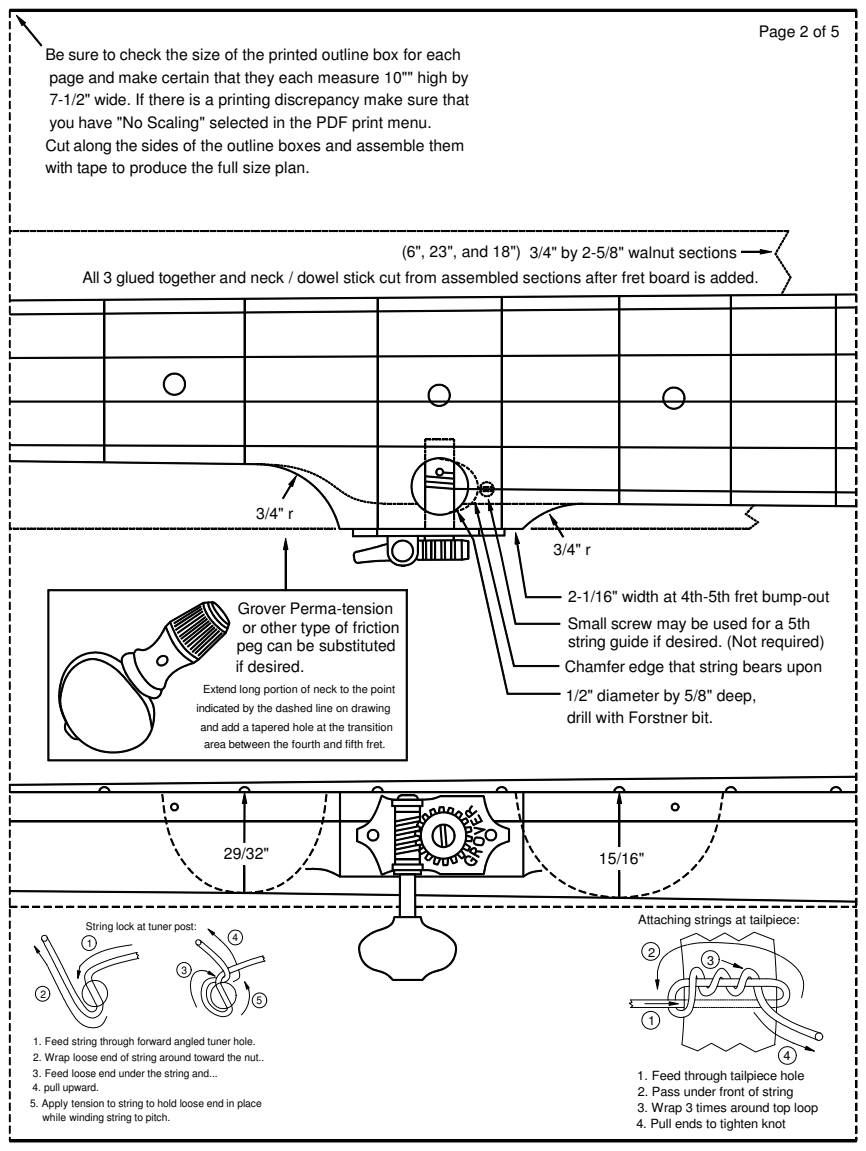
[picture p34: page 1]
Page 2 of 5

Be sure to check the size of the printed outline box for each
page and make certain that they each measure 10"" high by
7-1/2" wide. If there is a printing discrepancy make sure that
you have "No Scaling" selected in the PDF print menu.
Cut along the sides of the outline boxes and assemble them
with tape to produce the full size plan.

(6", 23", and 18") 3/4" by 2-5/8" walnut sections

All 3 glued together and neck / dowel stick cut from assembled sections after fret board is added.

2-1/16" width at 4th-5th fret bump-out Grover Perma-tension

or other type of friction
peg can be substituted
if desired.

Small screw may be used for a 5th
string guide if desired. (Not required)
Chamfer edge that string bears upon
1/2" diameter by 5/8" deep,
drill with Forstner bit.

Extend long portion of neck to the point
indicated by the dashed line on drawing
and add a tapered hole at the transition
area between the fourth and fifth fret.

Attaching strings at tailpiece:

String lock at tuner post:

1. Feed string through forward angled tuner hole.
2. Wrap loose end of string around toward the nut..
3. Feed loose end under the string and...
4. pull upward.
5. Apply tension to string to hold loose end in place
while winding string to pitch.

1. Feed through tailpiece hole
2. Pass under front of string
3. Wrap 3 times around top loop
4. Pull ends to tighten knot

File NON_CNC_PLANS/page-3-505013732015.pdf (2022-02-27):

1 | 2 | 3

## Measurement of fret position distances:

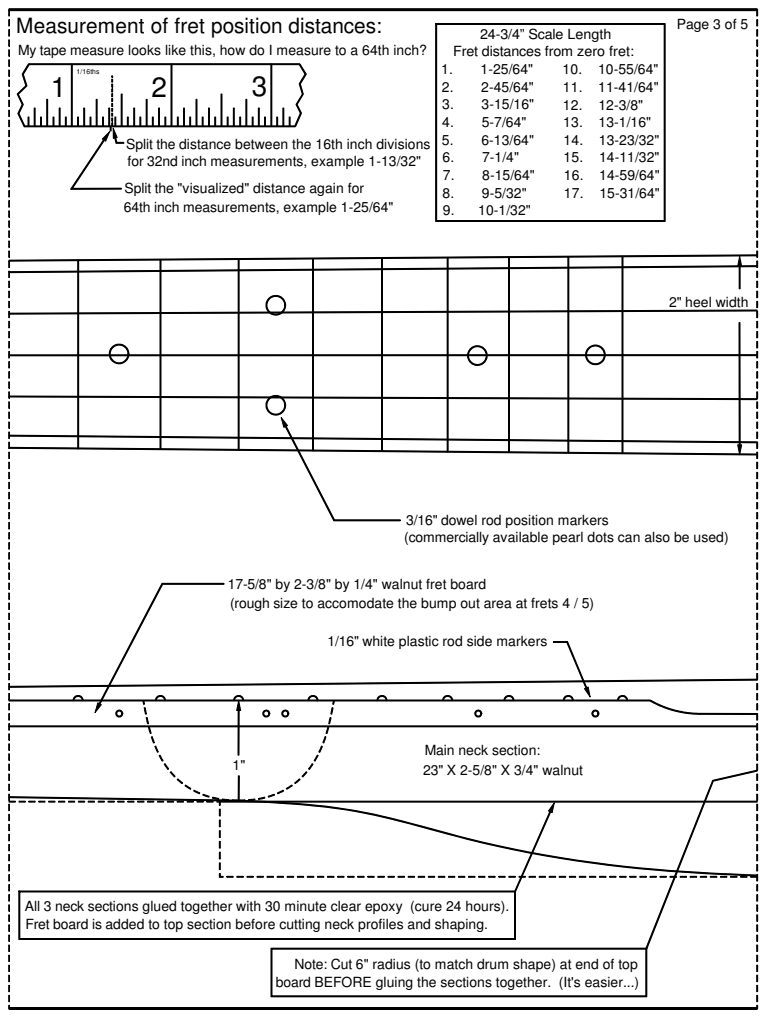
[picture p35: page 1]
1/16ths; 2" heel width; 24-3/4” Scale Length; Fret distances from zero fret:

My tape measure looks like this, how do I measure to a 64th inch?

Split the distance between the 16th inch divisions
for 32nd inch measurements, example 1-13/32"

Split the "visualized" distance again for
64th inch measurements, example 1-25/64"

3/16" dowel rod position markers
(commercially available pearl dots can also be used)

17-5/8" by 2-3/8" by 1/4" walnut fret board
(rough size to accomodate the bump out area at frets 4 / 5)

1/16" white plastic rod side markers

Main neck section:
23" X 2-5/8" X 3/4" walnut

All 3 neck sections glued together with 30 minute clear epoxy (cure 24 hours).
Fret board is added to top section before cutting neck profiles and shaping.

Note: Cut 6" radius (to match drum shape) at end of top
board BEFORE gluing the sections together. (It's easier...)

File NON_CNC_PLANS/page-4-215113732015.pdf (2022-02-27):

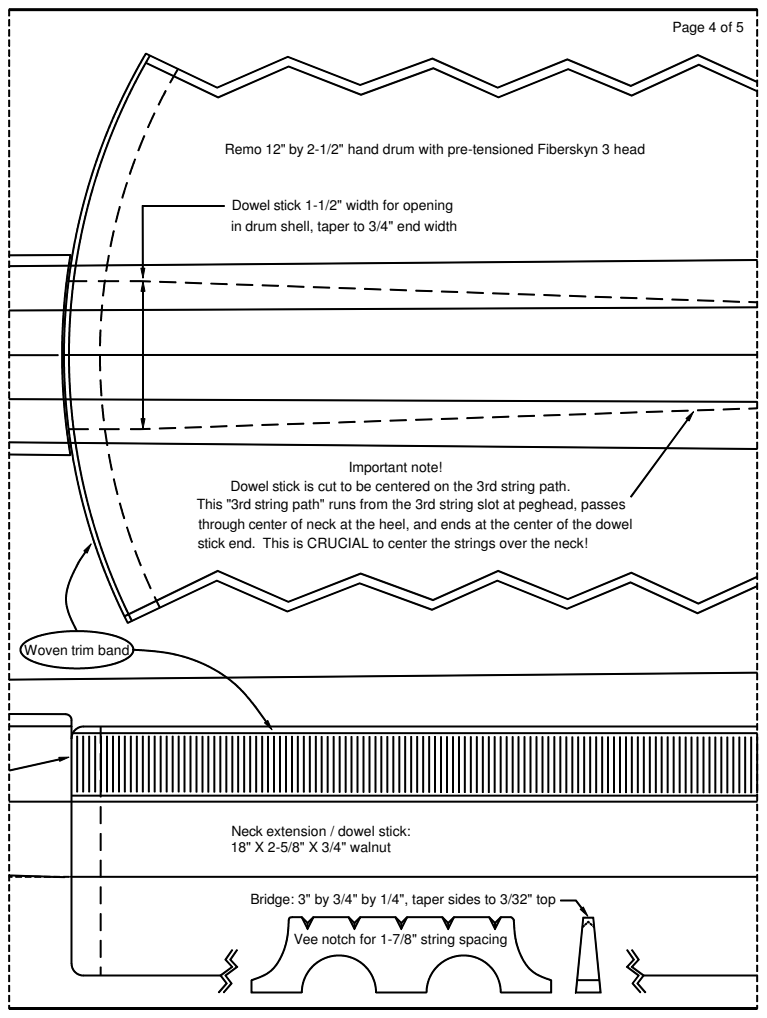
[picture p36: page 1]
Page 4 of 5; Important note!

Remo 12" by 2-1/2" hand drum with pre-tensioned Fiberskyn 3 head

Dowel stick 1-1/2" width for opening
in drum shell, taper to 3/4" end width

Dowel stick is cut to be centered on the 3rd string path.
This "3rd string path" runs from the 3rd string slot at peghead, passes
through center of neck at the heel, and ends at the center of the dowel
stick end. This is CRUCIAL to center the strings over the neck!

Woven trim band

Neck extension / dowel stick:
18" X 2-5/8" X 3/4" walnut

Bridge: 3" by 3/4" by 1/4", taper sides to 3/32" top

Vee notch for 1-7/8" string spacing

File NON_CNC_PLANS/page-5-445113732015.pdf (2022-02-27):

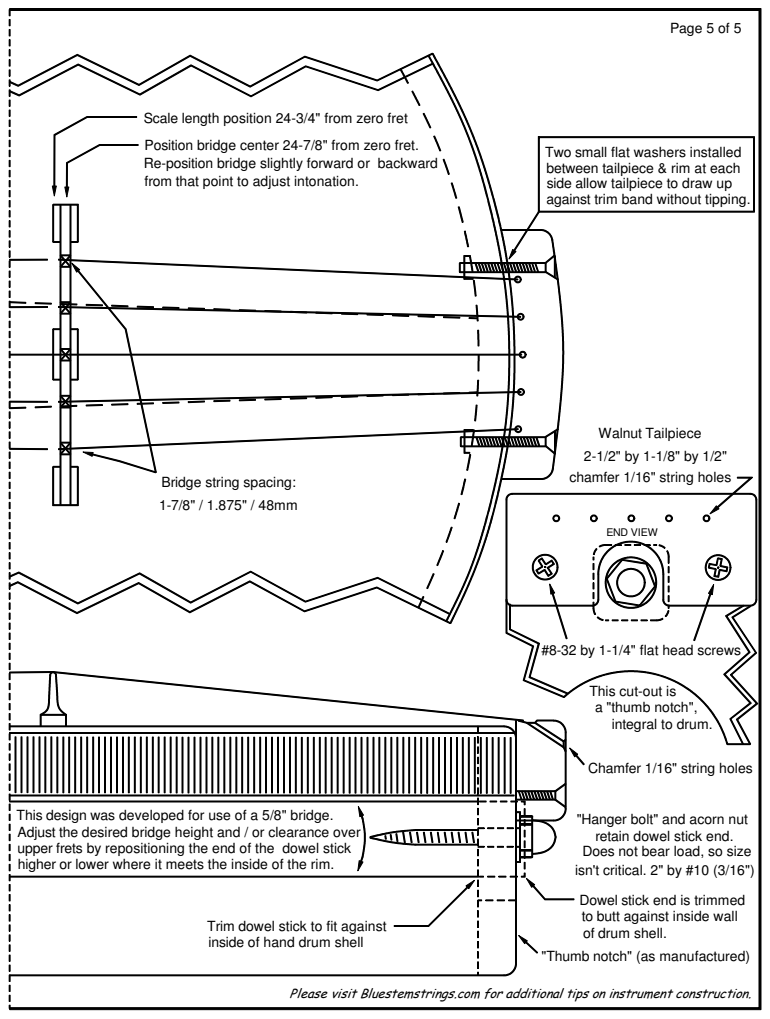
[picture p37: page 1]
Page 5 of 5; END VIEW; Walnut Tailpiece

Scale length position 24-3/4" from zero fret

Position bridge center 24-7/8" from zero fret.
Re-position bridge slightly forward or backward
from that point to adjust intonation.

Two small flat washers installed
between tailpiece & rim at each
side allow tailpiece to draw up
against trim band without tipping.

chamfer 1/16" string holes Bridge string spacing:

#8-32 by 1-1/4" flat head screws

This cut-out is
a "thumb notch",
integral to drum.

Chamfer 1/16" string holes

This design was developed for use of a 5/8" bridge.
Adjust the desired bridge height and / or clearance over
upper frets by repositioning the end of the dowel stick
higher or lower where it meets the inside of the rim.

"Hanger bolt" and acorn nut
retain dowel stick end.
Does not bear load, so size
isn't critical. 2" by #10 (3/16")

Dowel stick end is trimmed
to butt against inside wall
of drum shell.

Trim dowel stick to fit against
inside of hand drum shell

"Thumb notch" (as manufactured)

Please visit Bluestemstrings.com for additional tips on instrument construction.

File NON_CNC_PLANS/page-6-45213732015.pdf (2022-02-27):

## Bluestem Hand Drum Banjo Neck Layout

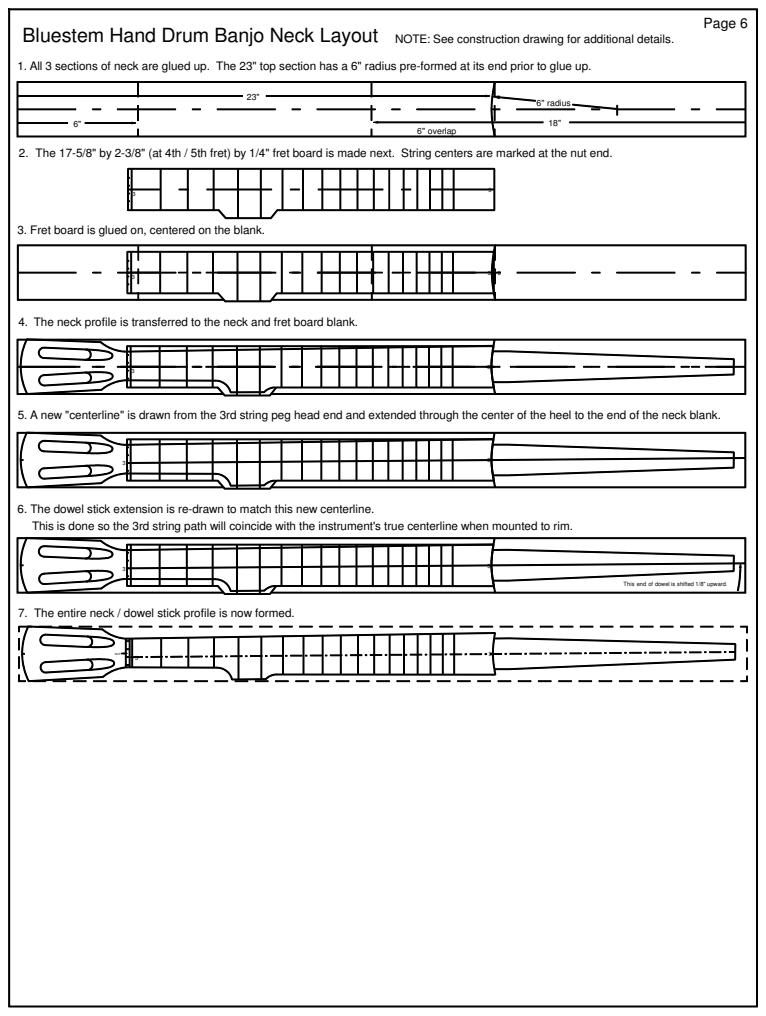
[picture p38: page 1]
6" overlap; 6" radius; NUT

NOTE: See construction drawing for additional details.

1. All 3 sections of neck are glued up. The 23" top section has a 6" radius pre-formed at its end prior to glue up.

2. The 17-5/8" by 2-3/8" (at 4th / 5th fret) by 1/4" fret board is made next. String centers are marked at the nut end.

3. Fret board is glued on, centered on the blank.

4. The neck profile is transferred to the neck and fret board blank.

5. A new "centerline" is drawn from the 3rd string peg head end and extended through the center of the heel to the end of the neck blank.

6. The dowel stick extension is re-drawn to match this new centerline.
This is done so the 3rd string path will coincide with the instrument's true centerline when mounted to rim.

This end of dowel is shifted 1/8" upward.

7. The entire neck / dowel stick profile is now formed.
